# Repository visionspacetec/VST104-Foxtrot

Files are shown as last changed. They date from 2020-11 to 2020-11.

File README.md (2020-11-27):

# VST104 Element Foxtrot - single MCU OBC for PC104
This repository contains the KiCad project and other documents created during the development of Element Foxtrot under [VST104 project](https://github.com/visionspacetec/VST104/). This FlatSat board is capable of hosting four PC104 format modules with LibreCube PC104 header pinout.

<p align="center">
  <br>
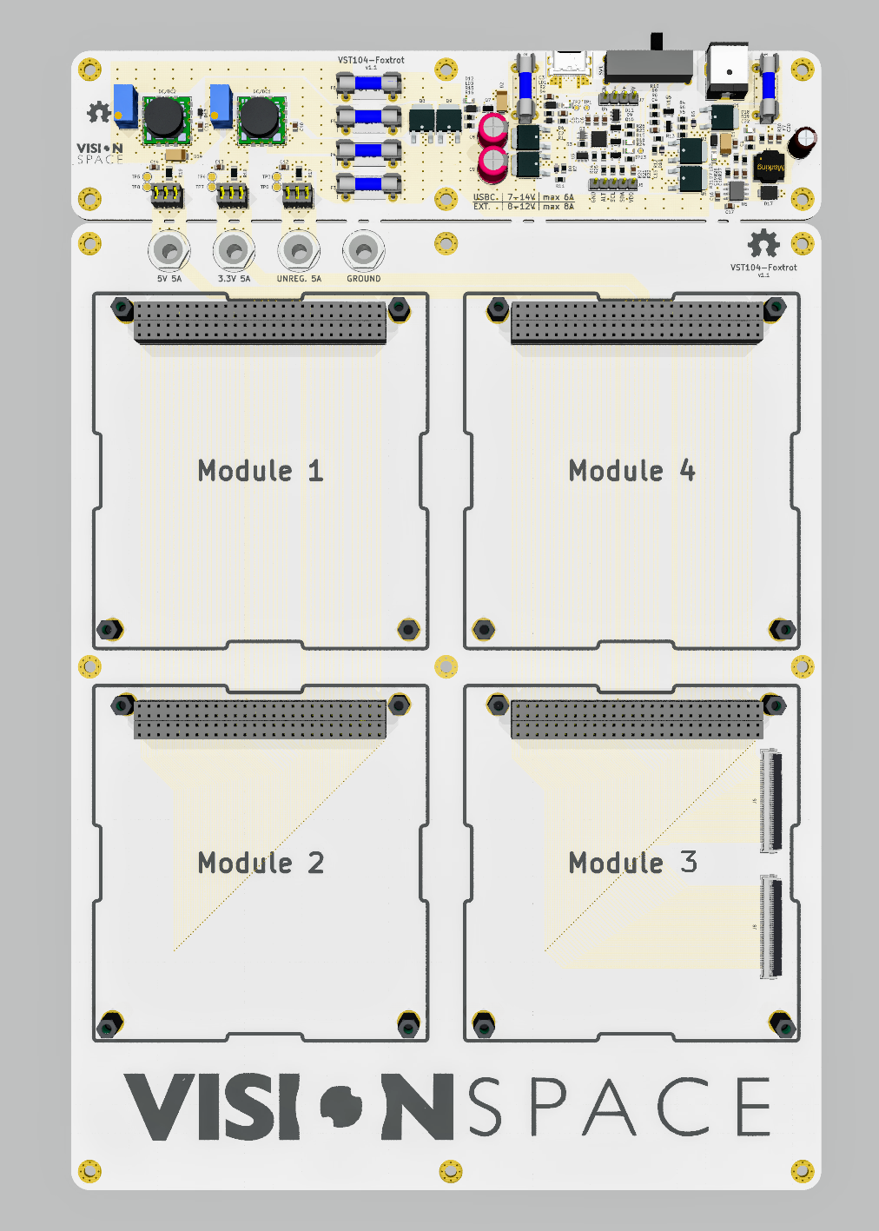
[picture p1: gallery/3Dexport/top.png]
  
  <br><br>
  <b>Fig 1.</b> Element Foxtrot 3D visualisation.
  <br><br>
</p>

## Basic specifications
* **`modules:`** This flatsat board can accommodate up to four PC104 modules. The position and orientation of these slots are marked with silkscreen contours. Headers of the separate slots are connected in between each other concerning individual pins. Tracing of power lines is strengthened, and the ground is shared with the rest of the board.
* **`power circuitry:`** Upper part of the board carries power distribution circuitry. Power outputs of this part are connected to corresponding powerlines of PC104 slots. The usual setup is: **3.3[V], 5[V] and unregulated** - individually rated to deliver up to **5[A]** (depends on power source) to these power lines. Although different voltages in the regulated powerlines can be set by trimmers.
* **`power modes:`** A user can power this flatsat in two different modes. External power supply with standard **2[mm] JACK** or **USB-C** charger. A three-position slide switch *(on/off/on)* placed between these two connectors is used to select one or none of them. Both of the modes are rated for input voltage in range **7-14[V]** and input current up to **8[A]** for JACK mode and **6[A]** for USB-C mode.
* **`disconnection terminal:`** A set of removable jumpers is used to temporarily separate the power distribution circuitry from the rest of the flatsat. This is practical if a user needs to power the board from a different source or do not power it at all but is keen on not separating the power delivery circuitry by braking.
* **`4[mm] banana:`** After the disconnection terminal, just on the slots beginning, powerlines are placed a set of laboratory 2[mm] banana jacks. A user can use these jacks after disconnecting the corresponding terminals to point to any power or measuring device.

<p align="center">
  <br>
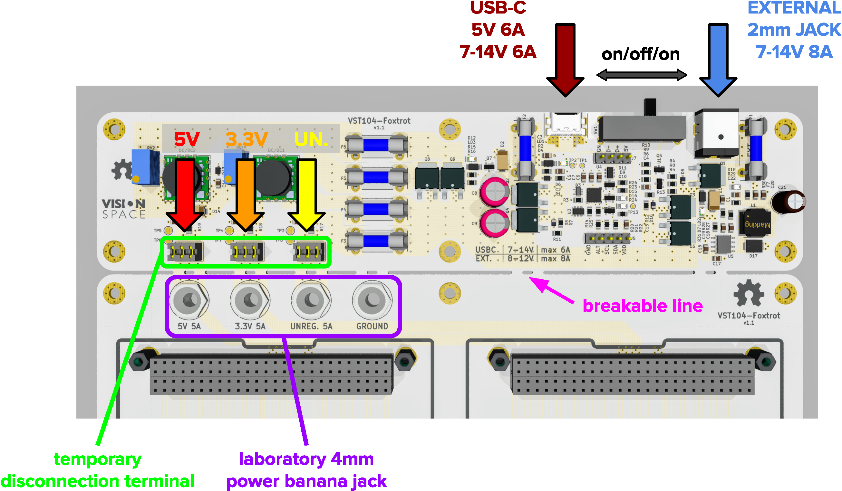
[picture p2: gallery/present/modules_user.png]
  
  <br><br>
  <b>Fig 1.</b> Graphical interpretation of segments described in "basic specifications" section.
  <br><br>
</p>

## Features

<p align="center">
  <br>
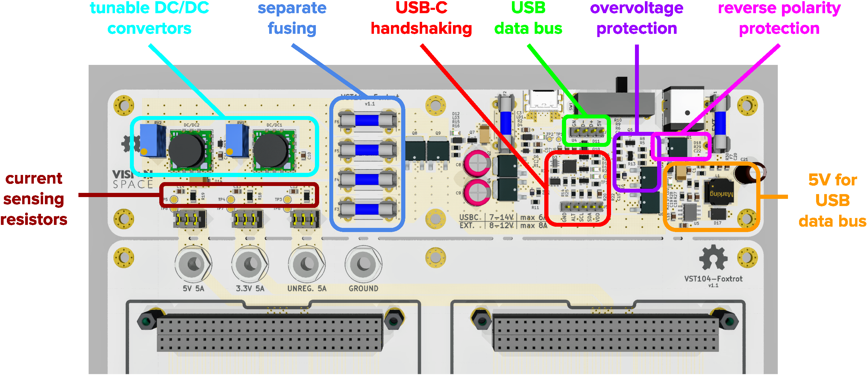
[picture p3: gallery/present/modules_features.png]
  
  <br><br>
  <b>Fig 1.</b> Graphical interpretation of segments described in "features" section.
  <br><br>
</p>

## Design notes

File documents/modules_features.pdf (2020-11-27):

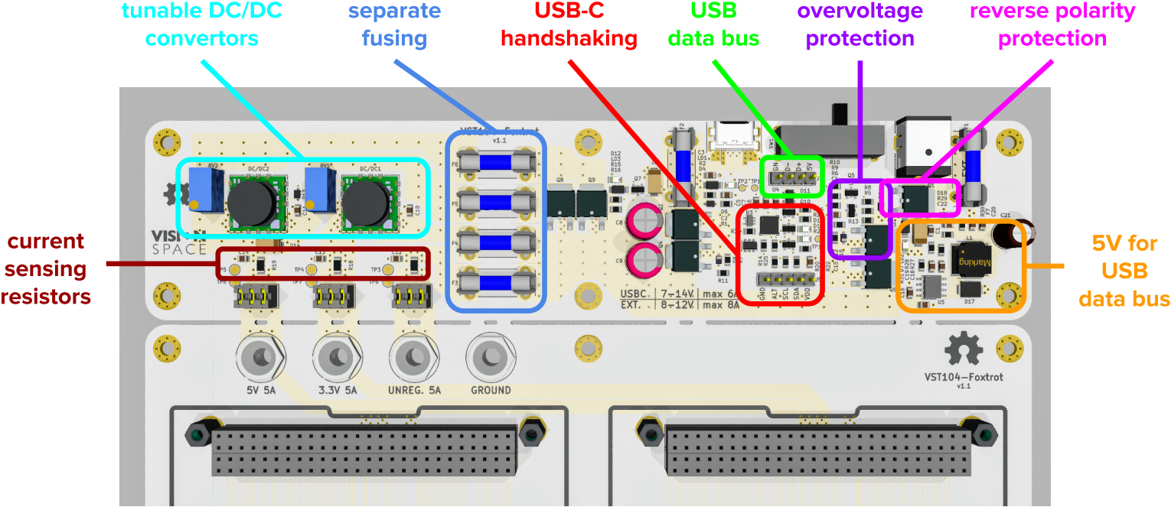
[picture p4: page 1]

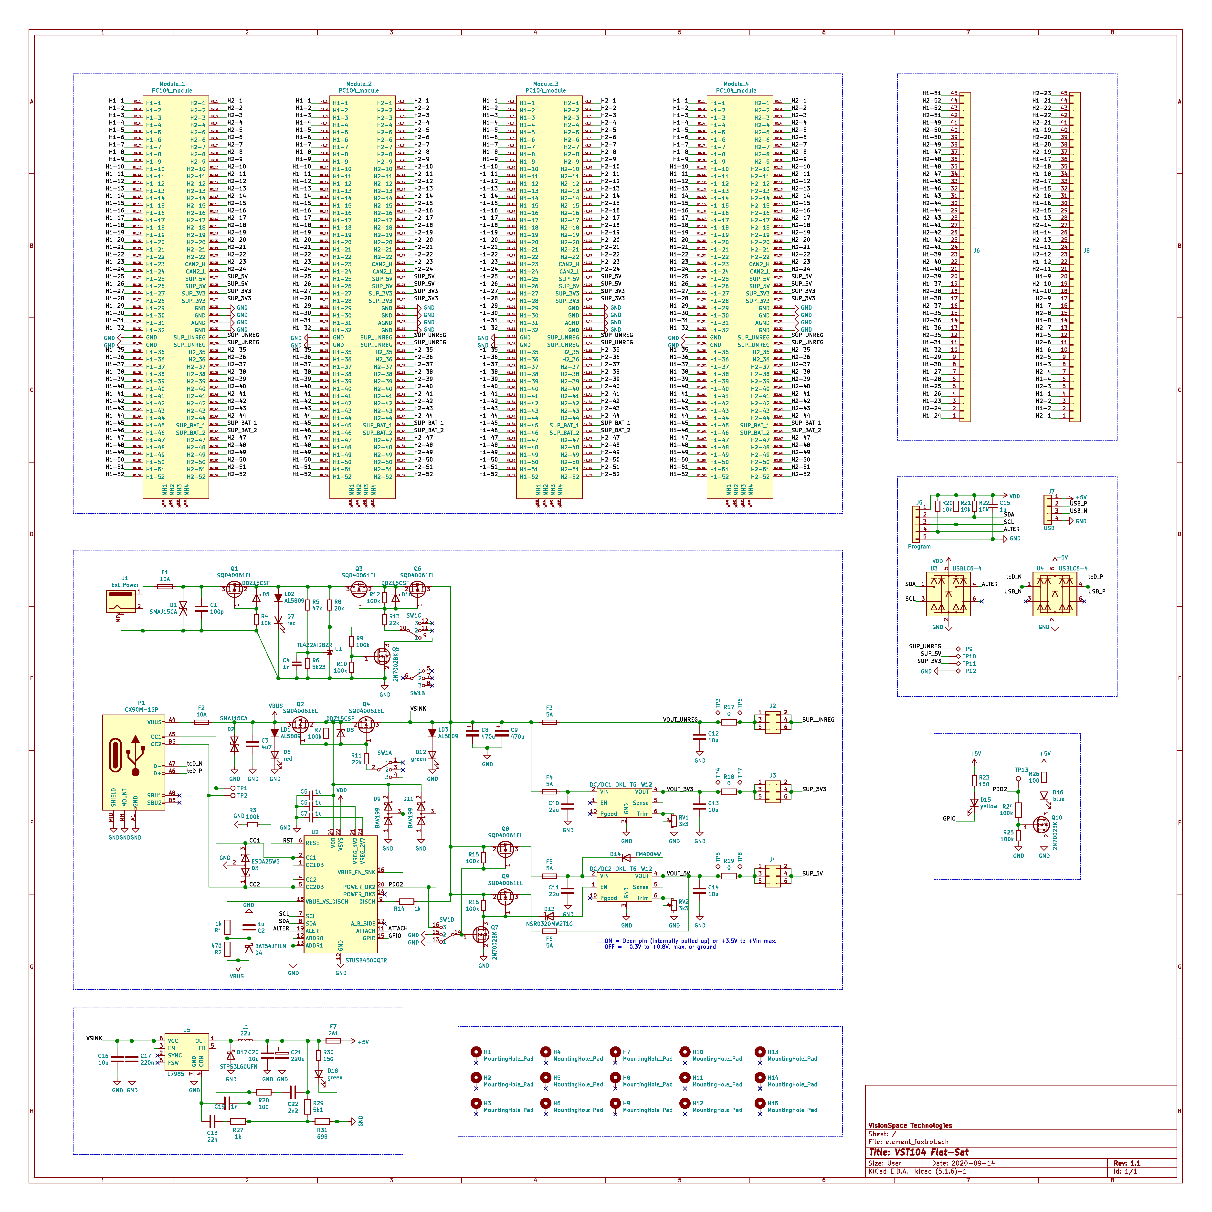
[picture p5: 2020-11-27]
gallery/present/schematic.png

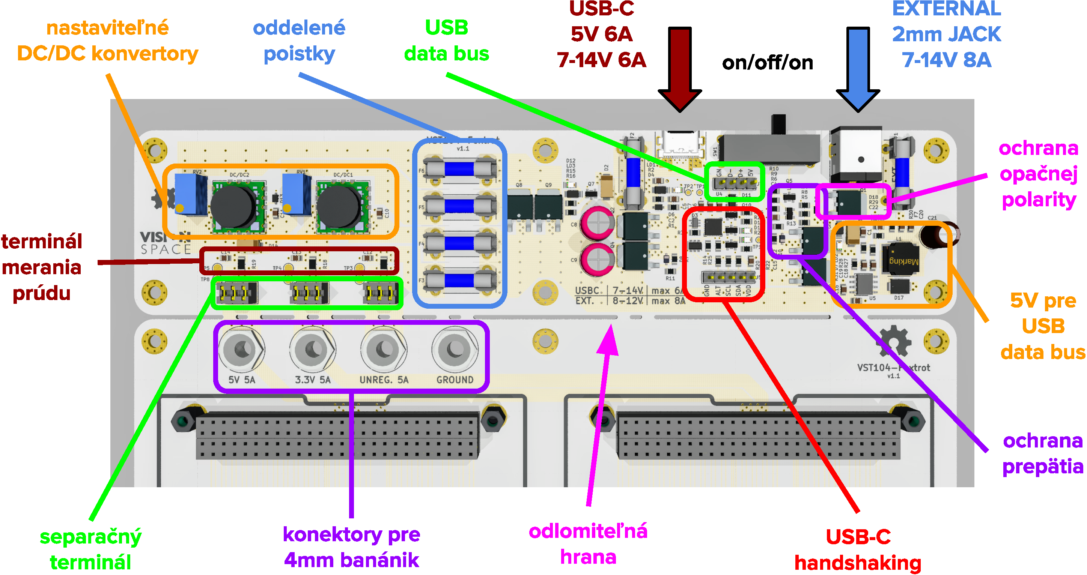
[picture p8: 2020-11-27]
gallery/present/modules_all.png

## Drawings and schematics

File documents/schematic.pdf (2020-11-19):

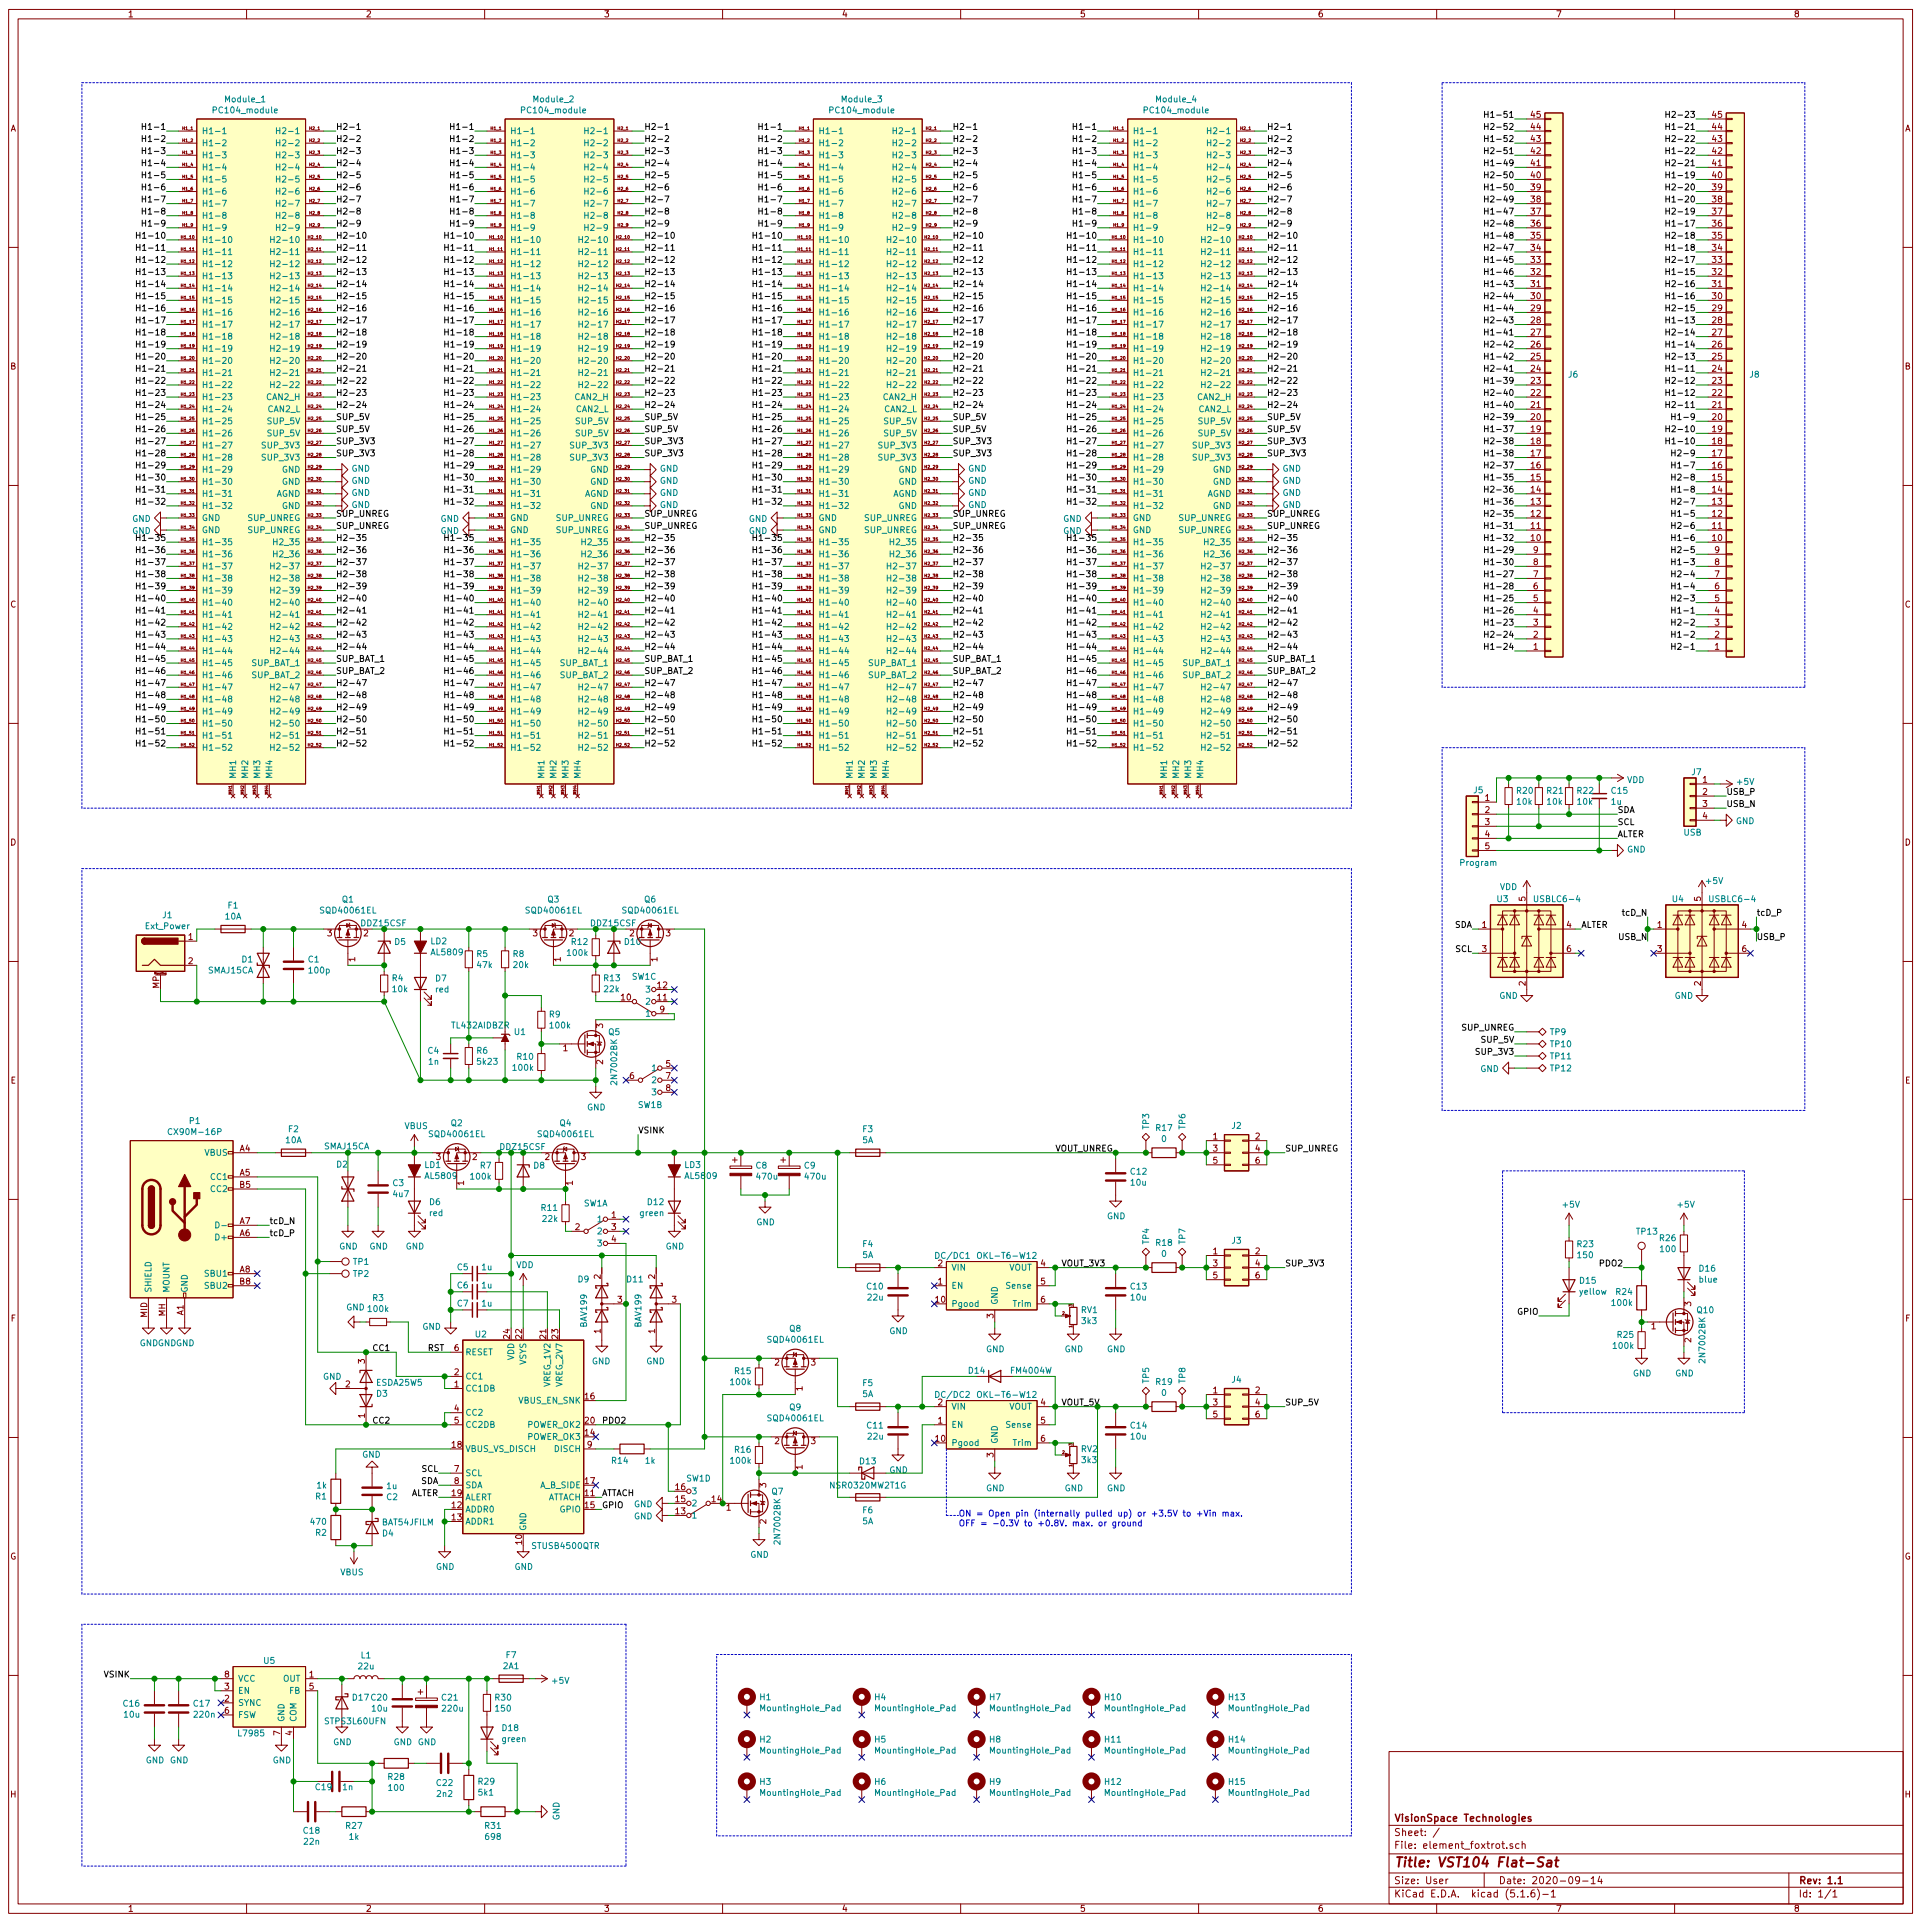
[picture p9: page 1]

3 VOUT 4 Sense 5 Trim 6 DC/DC2 OKL-T6-W12 VBUS GND GND

3 VOUT 4 Sense 5 Trim 6 DC/DC1 OKL-T6-W12

File: element_foxtrot.sch Sheet: / VisionSpace Technologies GND

ON = Open pin (internally pulled up) or +3.5V to +Vin max.
OFF = -0.3V to +0.8V. max. or ground

Id: 1/1 Title: VST104 Flat-Sat

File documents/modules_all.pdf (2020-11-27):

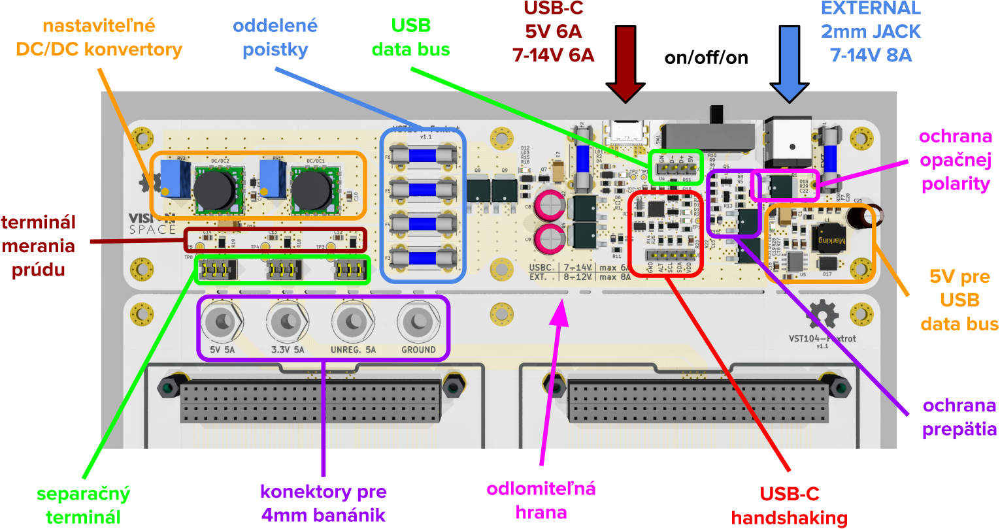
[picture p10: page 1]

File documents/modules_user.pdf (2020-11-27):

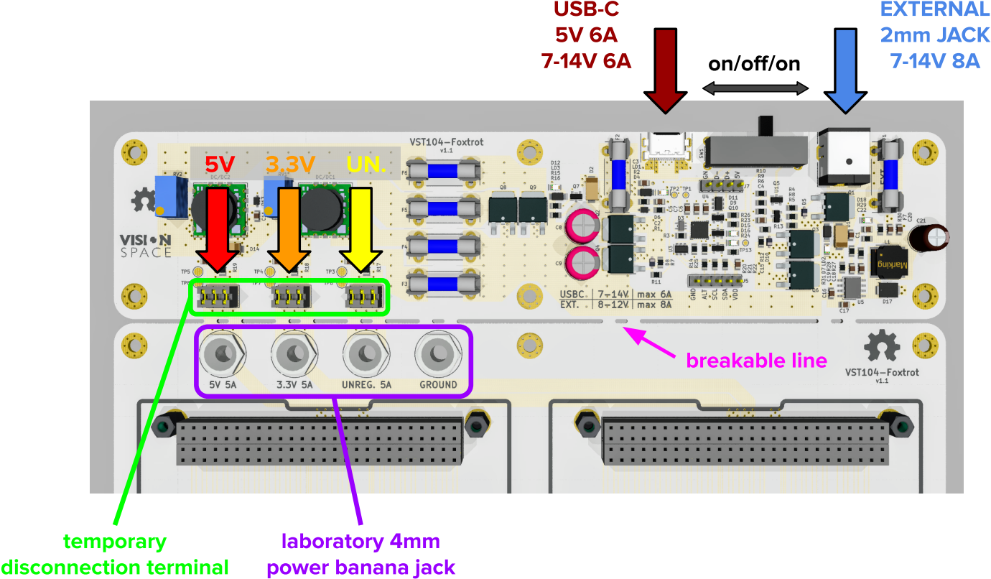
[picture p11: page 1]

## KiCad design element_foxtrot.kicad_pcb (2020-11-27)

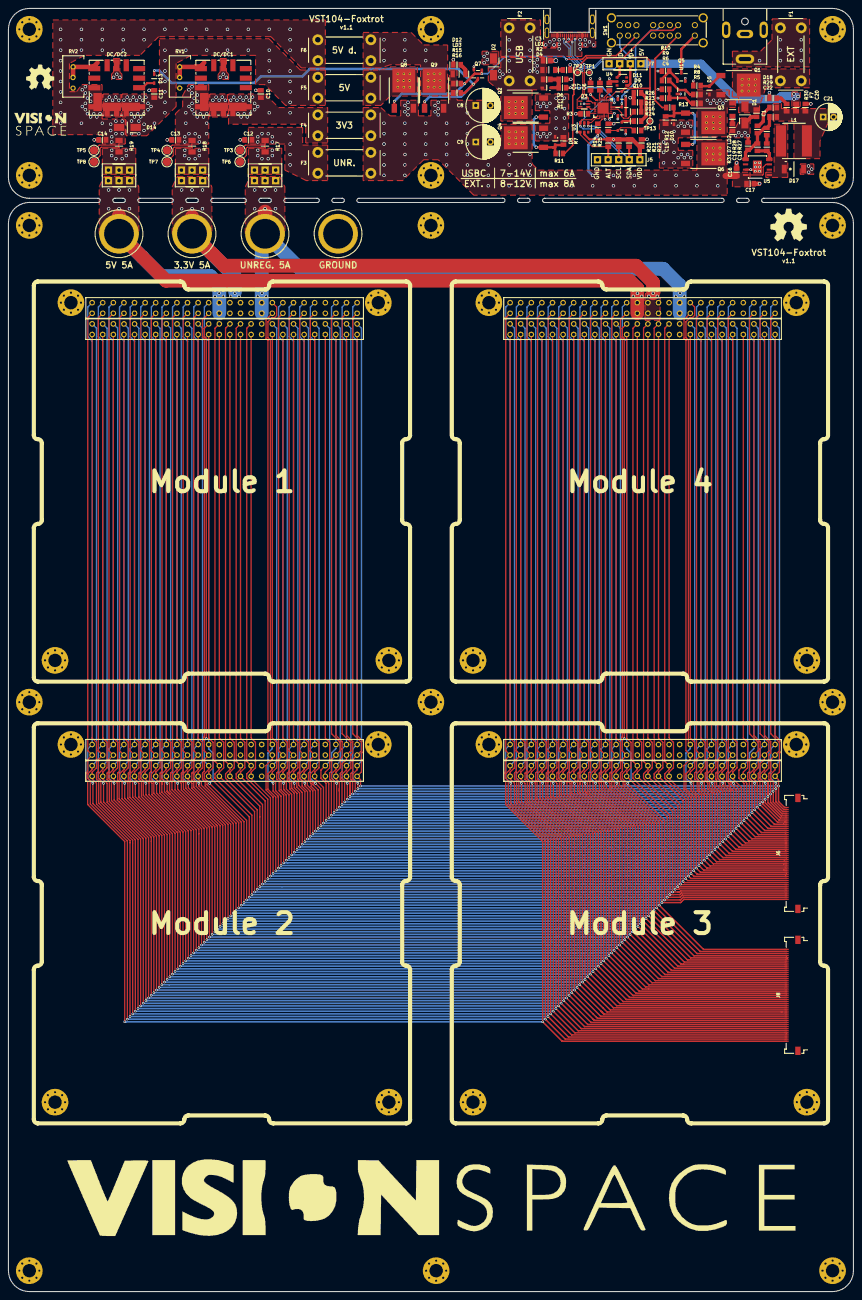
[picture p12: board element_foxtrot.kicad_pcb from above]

Board: 4 copper layers, 202.5 x 307.5 mm, 143 parts (0 on the bottom side), 160 nets.

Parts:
C1: 100p; C_SMD_0805
C2, C5, C6, C7, C15: 1u; C_SMD_0805
C3: 4u7; C_SMD_0805
C4, C19: 1n; C_SMD_0805
C8, C9: 470u; CP_Radial_D8.0mm_P3.50mm_L11.5mm
C10, C11: 22u; C_SMD_0805
C12, C13, C14, C16, C20: 10u; C_SMD_0805
C17: 220n; C_SMD_0805
C18: 22n; C_SMD_0805
C21: 220u; CP_Radial_D6.3mm_P2.50mm_L11.2mm
C22: 2n2; C_SMD_0805
D1, D2: SMAJ15CA; D_SMA_DO-214AC_4.3x2.6mm
D3: ESDA25W5; SOT-323-5L_2.0x1.25mm
D4: BAT54JFILM; D_SOD-323_1.65x1.28mm
D5, D8, D10: DDZ15CSF; D_SOD-323-F_1.25x1.7mm
D6, D7: red; D_SMD_0805_LED
D9, D11: BAV199; SOT-23-3_2.9x1.3mm
D12, D18: green; D_SMD_0805_LED
D13: NSR0320MW2T1G; D_SOD-323_1.65x1.28mm
D14: FM4004W; D_SMA_DO-214AC_4.3x2.6mm
D15: yellow; D_SMD_0805_LED
D16: blue; D_SMD_0805_LED
D17: STPS3L60UFN; D_SMB-FN_DO-214AA-FN
DC/DC1, DC/DC2: Val**; OKL-T6-W12
F1, F2: 10A; FUSE_2AG_01110501Z
F3, F4, F5, F6: 5A; FUSE_2AG_01110501Z
F7: 2A1; C_SMD_0805
H1, H2, H3, H4, H5, H6, H7, H8, H9, H10, H11, H12, H13, H14, H15: MountingHole_Pad; MountingHole_3.2mm_M3_Pad_Via
J1: Ext_Power; PJ-063AH
J2, J3, J4: Val**; TSW-103-07-x-D
J5: Program; TSW-105-07-x-S
J6, J8: Conn_01x45; conn_FPC_45x0.5_505110-4591
J7: USB; TSW-104-07-x-S
L1: 22u; L_SMD_8040_8.0x8.0x4.2mm
LD1, LD2, LD3: AL5809; Power-DI-123_2.8x1.8x1mm
Module_1, Module_2, Module_3, Module_4: PC104_module; PC104_footprint
P1: Val**; CX90M-16P
Q1, Q2, Q3, Q4, Q6, Q8, Q9: SQD40061EL; TO-252AA_6.5x6.1mm
Q5, Q7, Q10: 2N7002BK; SOT-23-3_2.9x1.3mm
R1, R14, R27: 1k; R_SMD_0805
R2: 470; R_SMD_0805
R3, R7, R9, R10, R12, R15, R16, R24, R25: 100k; R_SMD_0805
R4, R20, R21, R22: 10k; R_SMD_0805
R5: 47k; R_SMD_0805
R6: 5k23; R_SMD_0805
R8: 20k; R_SMD_0805
R11, R13: 22k; R_SMD_0805
R17, R18, R19: 0; R_SMD_1206
R23, R30: 150; R_SMD_0805
R26, R28: 100; R_SMD_0805
R29: 5k1; R_SMD_0805
R31: 698; R_SMD_0805
RV1, RV2: 3k3; trimer_3296W_10.0x9.5x10.0
SW1: EG4319A; EG4319
TP1, TP2, TP13: TestPoint; scope_PAD_1mm
TP3, TP4, TP5, TP6, TP7, TP8: TestPoint_Alt; scope_PAD_2mm
TP9, TP10, TP11, TP12: TestPoint_Alt; KSE_PN6095
U1: TL432AIDBZR; SOT-23-3_2.9x1.3mm
U2: STUSB4500QTR; QFN-24_4.0x4.0mm_EP
U3, U4: USBLC6-4; SOT-23-6L_2.9x1.6mm
U5: L7985; HSOP8_3.9x4.9mm_EP

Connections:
+5V: F7.1, J7.1, R23.1, R26.1, U4.5
/ALTER: J5.4, R20.2, U2.19, U3.4
/CC1: D3.3, P1.A5, TP1.1, U2.1, U2.2
/CC2: D3.1, P1.B5, TP2.1, U2.4, U2.5
/GPIO: D15.1, U2.15
/H1-1: J8.4, Module_1.H1_1, Module_2.H1_1, Module_3.H1_1, Module_4.H1_1
/H1-2: J8.2, Module_1.H1_2, Module_2.H1_2, Module_3.H1_2, Module_4.H1_2
/H1-3: J8.8, Module_1.H1_3, Module_2.H1_3, Module_3.H1_3, Module_4.H1_3
/H1-4: J8.6, Module_1.H1_4, Module_2.H1_4, Module_3.H1_4, Module_4.H1_4
/H1-5: J8.12, Module_1.H1_5, Module_2.H1_5, Module_3.H1_5, Module_4.H1_5
/H1-6: J8.10, Module_1.H1_6, Module_2.H1_6, Module_3.H1_6, Module_4.H1_6
/H1-7: J8.16, Module_1.H1_7, Module_2.H1_7, Module_3.H1_7, Module_4.H1_7
/H1-8: J8.14, Module_1.H1_8, Module_2.H1_8, Module_3.H1_8, Module_4.H1_8
/H1-9: J8.20, Module_1.H1_9, Module_2.H1_9, Module_3.H1_9, Module_4.H1_9
/H1-10: J8.18, Module_1.H1_10, Module_2.H1_10, Module_3.H1_10, Module_4.H1_10
/H1-11: J8.24, Module_1.H1_11, Module_2.H1_11, Module_3.H1_11, Module_4.H1_11
/H1-12: J8.22, Module_1.H1_12, Module_2.H1_12, Module_3.H1_12, Module_4.H1_12
/H1-13: J8.28, Module_1.H1_13, Module_2.H1_13, Module_3.H1_13, Module_4.H1_13
/H1-14: J8.26, Module_1.H1_14, Module_2.H1_14, Module_3.H1_14, Module_4.H1_14
/H1-15: J8.32, Module_1.H1_15, Module_2.H1_15, Module_3.H1_15, Module_4.H1_15
/H1-16: J8.30, Module_1.H1_16, Module_2.H1_16, Module_3.H1_16, Module_4.H1_16
/H1-17: J8.36, Module_1.H1_17, Module_2.H1_17, Module_3.H1_17, Module_4.H1_17
/H1-18: J8.34, Module_1.H1_18, Module_2.H1_18, Module_3.H1_18, Module_4.H1_18
/H1-19: J8.40, Module_1.H1_19, Module_2.H1_19, Module_3.H1_19, Module_4.H1_19
/H1-20: J8.38, Module_1.H1_20, Module_2.H1_20, Module_3.H1_20, Module_4.H1_20
/H1-21: J8.44, Module_1.H1_21, Module_2.H1_21, Module_3.H1_21, Module_4.H1_21
/H1-22: J8.42, Module_1.H1_22, Module_2.H1_22, Module_3.H1_22, Module_4.H1_22
/H1-23: J6.3, Module_1.H1_23, Module_2.H1_23, Module_3.H1_23, Module_4.H1_23
/H1-24: J6.1, Module_1.H1_24, Module_2.H1_24, Module_3.H1_24, Module_4.H1_24
/H1-25: J6.5, Module_1.H1_25, Module_2.H1_25, Module_3.H1_25, Module_4.H1_25
/H1-26: J6.4, Module_1.H1_26, Module_2.H1_26, Module_3.H1_26, Module_4.H1_26
/H1-27: J6.7, Module_1.H1_27, Module_2.H1_27, Module_3.H1_27, Module_4.H1_27
/H1-28: J6.6, Module_1.H1_28, Module_2.H1_28, Module_3.H1_28, Module_4.H1_28
/H1-29: J6.9, Module_1.H1_29, Module_2.H1_29, Module_3.H1_29, Module_4.H1_29
/H1-30: J6.8, Module_1.H1_30, Module_2.H1_30, Module_3.H1_30, Module_4.H1_30
/H1-31: J6.11, Module_1.H1_31, Module_2.H1_31, Module_3.H1_31, Module_4.H1_31
/H1-32: J6.10, Module_1.H1_32, Module_2.H1_32, Module_3.H1_32, Module_4.H1_32
/H1-35: J6.15, Module_1.H1_35, Module_2.H1_35, Module_3.H1_35, Module_4.H1_35
/H1-36: J6.13, Module_1.H1_36, Module_2.H1_36, Module_3.H1_36, Module_4.H1_36
/H1-37: J6.19, Module_1.H1_37, Module_2.H1_37, Module_3.H1_37, Module_4.H1_37
/H1-38: J6.17, Module_1.H1_38, Module_2.H1_38, Module_3.H1_38, Module_4.H1_38
/H1-39: J6.23, Module_1.H1_39, Module_2.H1_39, Module_3.H1_39, Module_4.H1_39
/H1-40: J6.21, Module_1.H1_40, Module_2.H1_40, Module_3.H1_40, Module_4.H1_40
/H1-41: J6.27, Module_1.H1_41, Module_2.H1_41, Module_3.H1_41, Module_4.H1_41
/H1-42: J6.25, Module_1.H1_42, Module_2.H1_42, Module_3.H1_42, Module_4.H1_42
/H1-43: J6.31, Module_1.H1_43, Module_2.H1_43, Module_3.H1_43, Module_4.H1_43
/H1-44: J6.29, Module_1.H1_44, Module_2.H1_44, Module_3.H1_44, Module_4.H1_44
/H1-45: J6.33, Module_1.H1_45, Module_2.H1_45, Module_3.H1_45, Module_4.H1_45
/H1-46: J6.32, Module_1.H1_46, Module_2.H1_46, Module_3.H1_46, Module_4.H1_46
/H1-47: J6.37, Module_1.H1_47, Module_2.H1_47, Module_3.H1_47, Module_4.H1_47
/H1-48: J6.35, Module_1.H1_48, Module_2.H1_48, Module_3.H1_48, Module_4.H1_48
/H1-49: J6.41, Module_1.H1_49, Module_2.H1_49, Module_3.H1_49, Module_4.H1_49
/H1-50: J6.39, Module_1.H1_50, Module_2.H1_50, Module_3.H1_50, Module_4.H1_50
/H1-51: J6.45, Module_1.H1_51, Module_2.H1_51, Module_3.H1_51, Module_4.H1_51
/H1-52: J6.43, Module_1.H1_52, Module_2.H1_52, Module_3.H1_52, Module_4.H1_52
/H2-1: J8.1, Module_1.H2_1, Module_2.H2_1, Module_3.H2_1, Module_4.H2_1
/H2-2: J8.3, Module_1.H2_2, Module_2.H2_2, Module_3.H2_2, Module_4.H2_2
/H2-3: J8.5, Module_1.H2_3, Module_2.H2_3, Module_3.H2_3, Module_4.H2_3
/H2-4: J8.7, Module_1.H2_4, Module_2.H2_4, Module_3.H2_4, Module_4.H2_4
/H2-5: J8.9, Module_1.H2_5, Module_2.H2_5, Module_3.H2_5, Module_4.H2_5
/H2-6: J8.11, Module_1.H2_6, Module_2.H2_6, Module_3.H2_6, Module_4.H2_6
/H2-7: J8.13, Module_1.H2_7, Module_2.H2_7, Module_3.H2_7, Module_4.H2_7
/H2-8: J8.15, Module_1.H2_8, Module_2.H2_8, Module_3.H2_8, Module_4.H2_8
/H2-9: J8.17, Module_1.H2_9, Module_2.H2_9, Module_3.H2_9, Module_4.H2_9
/H2-10: J8.19, Module_1.H2_10, Module_2.H2_10, Module_3.H2_10, Module_4.H2_10
/H2-11: J8.21, Module_1.H2_11, Module_2.H2_11, Module_3.H2_11, Module_4.H2_11
/H2-12: J8.23, Module_1.H2_12, Module_2.H2_12, Module_3.H2_12, Module_4.H2_12
/H2-13: J8.25, Module_1.H2_13, Module_2.H2_13, Module_3.H2_13, Module_4.H2_13
/H2-14: J8.27, Module_1.H2_14, Module_2.H2_14, Module_3.H2_14, Module_4.H2_14
/H2-15: J8.29, Module_1.H2_15, Module_2.H2_15, Module_3.H2_15, Module_4.H2_15
/H2-16: J8.31, Module_1.H2_16, Module_2.H2_16, Module_3.H2_16, Module_4.H2_16
/H2-17: J8.33, Module_1.H2_17, Module_2.H2_17, Module_3.H2_17, Module_4.H2_17
/H2-18: J8.35, Module_1.H2_18, Module_2.H2_18, Module_3.H2_18, Module_4.H2_18
/H2-19: J8.37, Module_1.H2_19, Module_2.H2_19, Module_3.H2_19, Module_4.H2_19
/H2-20: J8.39, Module_1.H2_20, Module_2.H2_20, Module_3.H2_20, Module_4.H2_20
/H2-21: J8.41, Module_1.H2_21, Module_2.H2_21, Module_3.H2_21, Module_4.H2_21
/H2-22: J8.43, Module_1.H2_22, Module_2.H2_22, Module_3.H2_22, Module_4.H2_22
/H2-23: J8.45, Module_1.H2_23, Module_2.H2_23, Module_3.H2_23, Module_4.H2_23
/H2-24: J6.2, Module_1.H2_24, Module_2.H2_24, Module_3.H2_24, Module_4.H2_24
/H2-35: J6.12, Module_1.H2_35, Module_2.H2_35, Module_3.H2_35, Module_4.H2_35
/H2-36: J6.14, Module_1.H2_36, Module_2.H2_36, Module_3.H2_36, Module_4.H2_36
/H2-37: J6.16, Module_1.H2_37, Module_2.H2_37, Module_3.H2_37, Module_4.H2_37
/H2-38: J6.18, Module_1.H2_38, Module_2.H2_38, Module_3.H2_38, Module_4.H2_38
/H2-39: J6.20, Module_1.H2_39, Module_2.H2_39, Module_3.H2_39, Module_4.H2_39
/H2-40: J6.22, Module_1.H2_40, Module_2.H2_40, Module_3.H2_40, Module_4.H2_40
/H2-41: J6.24, Module_1.H2_41, Module_2.H2_41, Module_3.H2_41, Module_4.H2_41
/H2-42: J6.26, Module_1.H2_42, Module_2.H2_42, Module_3.H2_42, Module_4.H2_42
/H2-43: J6.28, Module_1.H2_43, Module_2.H2_43, Module_3.H2_43, Module_4.H2_43
/H2-44: J6.30, Module_1.H2_44, Module_2.H2_44, Module_3.H2_44, Module_4.H2_44
/H2-47: J6.34, Module_1.H2_47, Module_2.H2_47, Module_3.H2_47, Module_4.H2_47
/H2-48: J6.36, Module_1.H2_48, Module_2.H2_48, Module_3.H2_48, Module_4.H2_48
/H2-49: J6.38, Module_1.H2_49, Module_2.H2_49, Module_3.H2_49, Module_4.H2_49
/H2-50: J6.40, Module_1.H2_50, Module_2.H2_50, Module_3.H2_50, Module_4.H2_50
/H2-51: J6.42, Module_1.H2_51, Module_2.H2_51, Module_3.H2_51, Module_4.H2_51
/H2-52: J6.44, Module_1.H2_52, Module_2.H2_52, Module_3.H2_52, Module_4.H2_52
/PDO2: D11.3, R24.2, SW1.16, TP13.1, U2.20
/RST: R3.2, U2.6
/SCL: J5.3, R21.2, U2.7, U3.3
/SDA: J5.2, R22.2, U2.8, U3.1
/SUP_3V3: J3.2, J3.4, J3.6, Module_1.H2_27, Module_1.H2_28, Module_2.H2_27, Module_2.H2_28, Module_3.H2_27, Module_3.H2_28, Module_4.H2_27, Module_4.H2_28, TP11.1
/SUP_5V: J4.2, J4.4, J4.6, Module_1.H2_25, Module_1.H2_26, Module_2.H2_25, Module_2.H2_26, Module_3.H2_25, Module_3.H2_26, Module_4.H2_25, Module_4.H2_26, TP10.1
/SUP_BAT_1: Module_1.H2_45, Module_2.H2_45, Module_3.H2_45, Module_4.H2_45
/SUP_BAT_2: Module_1.H2_46, Module_2.H2_46, Module_3.H2_46, Module_4.H2_46
/SUP_UNREG: J2.2, J2.4, J2.6, Module_1.H2_33, Module_1.H2_34, Module_2.H2_33, Module_2.H2_34, Module_3.H2_33, Module_3.H2_34, Module_4.H2_33, Module_4.H2_34, TP9.1
/USB_N: J7.3, P1.A7, P1.B7, U4.1
/USB_P: J7.2, P1.A6, P1.B6, U4.4
/VOUT_3V3: C13.1, DC/DC1.4, DC/DC1.5, R18.2, TP4.1
/VOUT_5V: C14.1, D14.2, DC/DC2.4, DC/DC2.5, F6.1, R19.2, TP5.1
/VOUT_UNREG: C12.1, F3.1, R17.2, TP3.1
/VSINK: C8.1, C9.1, C16.1, C17.1, F3.2, F4.2, LD3.2, Q4.3, Q6.3, Q8.2, Q9.2, R14.2, R15.1, R16.1, U5.3, U5.8
GND: C1.1, C2.1, C3.1, C4.2, C5.1, C6.1, C7.1, C8.2, C9.2, C10.2, C11.2, C12.2, C13.2, C14.2, C15.2, C16.2, C17.2, C20.2, C21.2, D1.1, D2.1, D3.2, D6.1, D7.1, D9.1, D11.1, D12.1, D17.2, D18.1, DC/DC1.3, DC/DC1.7, DC/DC2.3, DC/DC2.7, J1.2, J1.MP, J5.5, J7.4, Module_1.H1_33, Module_1.H1_34, Module_1.H2_29, Module_1.H2_30, Module_1.H2_31, Module_1.H2_32, Module_2.H1_33, Module_2.H1_34, Module_2.H2_29, Module_2.H2_30, Module_2.H2_31, Module_2.H2_32, Module_3.H1_33, Module_3.H1_34, Module_3.H2_29, Module_3.H2_30, Module_3.H2_31, Module_3.H2_32, Module_4.H1_33, Module_4.H1_34, Module_4.H2_29, Module_4.H2_30, Module_4.H2_31, Module_4.H2_32, P1.A1, P1.A12, P1.B1, P1.B12, P1.MH, P1.MID, Q5.2, Q7.2, Q10.2, R3.1, R4.2, R6.2, R10.2, R25.2, R31.1, RV1.1, RV2.1, SW1.13, SW1.15, TP12.1, U1.3, U2.10, U2.12, U2.13, U2.25, U3.2, U4.2, U5.7, U5.25
unnamed: C1.2, D1.2, F1.1, Q1.3
unnamed: C2.2, D4.1, R1.1, R2.2
unnamed: C4.1, R5.2, R6.1, U1.1
unnamed: C5.2, D8.1, D9.2, D11.2, Q2.2, Q4.2, R7.1, U2.24
unnamed: C6.2, U2.21
unnamed: C7.2, U2.23
unnamed: C10.1, DC/DC1.2, F4.1
unnamed: C11.1, D14.1, DC/DC2.2, F5.1
unnamed: C18.1, C19.1, U5.4
unnamed: C18.2, R27.2
unnamed: C19.2, R27.1, R28.1, R29.1, R31.2, U5.5
unnamed: C20.1, C21.1, C22.1, F7.2, L1.2, R29.2, R30.1
unnamed: C22.2, R28.2
unnamed: D5.1, LD2.2, Q1.2, Q3.3, R5.1, R8.1
unnamed: D5.2, Q1.1, R4.1
unnamed: D6.2, LD1.1
unnamed: D7.2, LD2.1
unnamed: D8.2, Q2.1, Q4.1, R7.2, R11.1
unnamed: D9.3, SW1.4, U2.16
unnamed: D10.1, Q3.2, Q6.2, R12.1
unnamed: D10.2, Q3.1, Q6.1, R12.2, R13.1
unnamed: D12.2, LD3.1
unnamed: D13.1, Q7.3, Q9.1, R16.2
unnamed: D13.2, DC/DC2.1
unnamed: D15.2, R23.2
unnamed: D16.1, Q10.3
unnamed: D16.2, R26.2
unnamed: D17.1, L1.1, U5.1
unnamed: D18.2, R30.2
unnamed: DC/DC1.6, RV1.2, RV1.3
unnamed: DC/DC2.6, RV2.2, RV2.3
unnamed: F1.2, J1.1
unnamed: F2.2, P1.A4, P1.A9, P1.B4, P1.B9
unnamed: F5.2, Q8.3
unnamed: F6.2, Q9.3
unnamed: J2.1, J2.3, J2.5, R17.1, TP6.1
unnamed: J3.1, J3.3, J3.5, R18.1, TP7.1
unnamed: J4.1, J4.3, J4.5, R19.1, TP8.1
unnamed: Q5.1, R9.2, R10.1
unnamed: Q5.3, SW1.9
unnamed: Q7.1, Q8.1, R15.2, SW1.14
unnamed: Q10.1, R24.1, R25.1
unnamed: R1.2, U2.18
unnamed: R8.2, R9.1, U1.2
unnamed: R11.2, SW1.2
unnamed: R13.2, SW1.10
unnamed: R14.1, U2.9
VBUS: C3.2, D2.2, D4.2, F2.1, LD1.2, Q2.3, R2.1
VDD: C15.1, J5.1, R20.1, R21.1, R22.1, U2.22, U3.5
